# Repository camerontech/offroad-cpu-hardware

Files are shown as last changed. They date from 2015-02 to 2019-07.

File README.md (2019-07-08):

# Cameron Tech Offroad CPU

Here is the Eagle schematic and board layout for the CTAIM1. Software can be found here: https://github.com/camerontech/offroad-cpu

If picking up and assembling all of these parts yourself is a bit daunting, you can purchase a kit or pre-assembled
unit here: http://store.camerontech.io/products/offroad-cpu

Schematic

## Parts

**1 x ATMEGA328P-PU** [ATMEGA 328](http://amzn.to/2iHWBoK)

**1 x LCD** [SparkFun LCD-00709](https://www.sparkfun.com/products/709)

**1 x Multi-sensor** [10DOF Board](https://www.amazon.com/SUNKEE-1232055-Attitude-Indicator-L3G4200D/dp/B00CD239UG)

**1 x 5v Regulator** [Digikey MC7805CT-BPMS-ND]( http://www.digikey.com/product-search/en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)

**1 x 16MHz Clock Crystal** [Mouser 815-ABL-16-B2](http://www.mouser.com/Search/ProductDetail.aspx?R=ABL-16.000MHZ-B2virtualkey52750000virtualkey815-ABL-16-B2)

**1 x 10kΩ Potentiometer** [Digikey D4AA14-ND](http://www.digikey.com/product-search/en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)

**2 x 10µF Capacitor** [Digikey P975-ND](http://www.digikey.com/product-search/en/capacitors/aluminum-capacitors/131081?k=p975-ND)

**1 x 0.1F Capacitor** [Digikey 399-4266-ND](http://www.digikey.com/product-search/en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)

**2 x 22pF Capacitor** [Digikey 399-9723-ND](http://www.digikey.com/product-detail/en/C315C220K5G5TA/399-9723-ND/3726119)

**1 x NPN Transistor** [Mouser 512-2N3904BU](http://www.mouser.com/Search/ProductDetail.aspx?R=2N3904BUvirtualkey51210000virtualkey512-2N3904BU)

**1 x 40-pin Straight Header** [SparkFun PRT-00116](https://www.sparkfun.com/products/116)

**1 x 40-pin Right-angle Header** [SparkFun PRT-00553](https://www.sparkfun.com/products/553)

**1 x Three-way switch** [Three-way Rocker Switch](https://www.sparkfun.com/products/8184)

**1 x Three-way switch breakout board** [Breakout Board](https://oshpark.com/shared_projects/Y3Nexyzu)

That'll get you everything you need to get it working. You'll still need to connect the three-way switch to the board
somehow and get power in. 

A 4-wire JST connector hooks up the three-way switch to the circuit and also lets you disconnect it:

**1 x 4-pin JST Connector** [SparkFun PRT-09916](https://www.sparkfun.com/products/9916)

You can solder 12v right to your circuit, or use a 9v battery. If you want something less permanent then use a screw
terminal so you can unhook the wires again if necessary:

**1 x 2-pin screw terminal** [SparkFun PRT-08432](https://www.sparkfun.com/products/8432)

**1 x 9v Battery Strap** [Digikey 81-8K-ND](http://www.digikey.com/product-detail/en/81-8/81-8K-ND/303954)

Finally, unless you want to do a lot of wire-routing and excess soldering by hand and manually following the 
schematic to hook everything up, you can also get the circuit board that lays everything out nicely and attaches 
as a backpack to the LCD screen:

**1 x Offroad CPU Circuit Board** [Cameron Tech CTORD100](https://oshpark.com/shared_projects/I7EZdFw5)

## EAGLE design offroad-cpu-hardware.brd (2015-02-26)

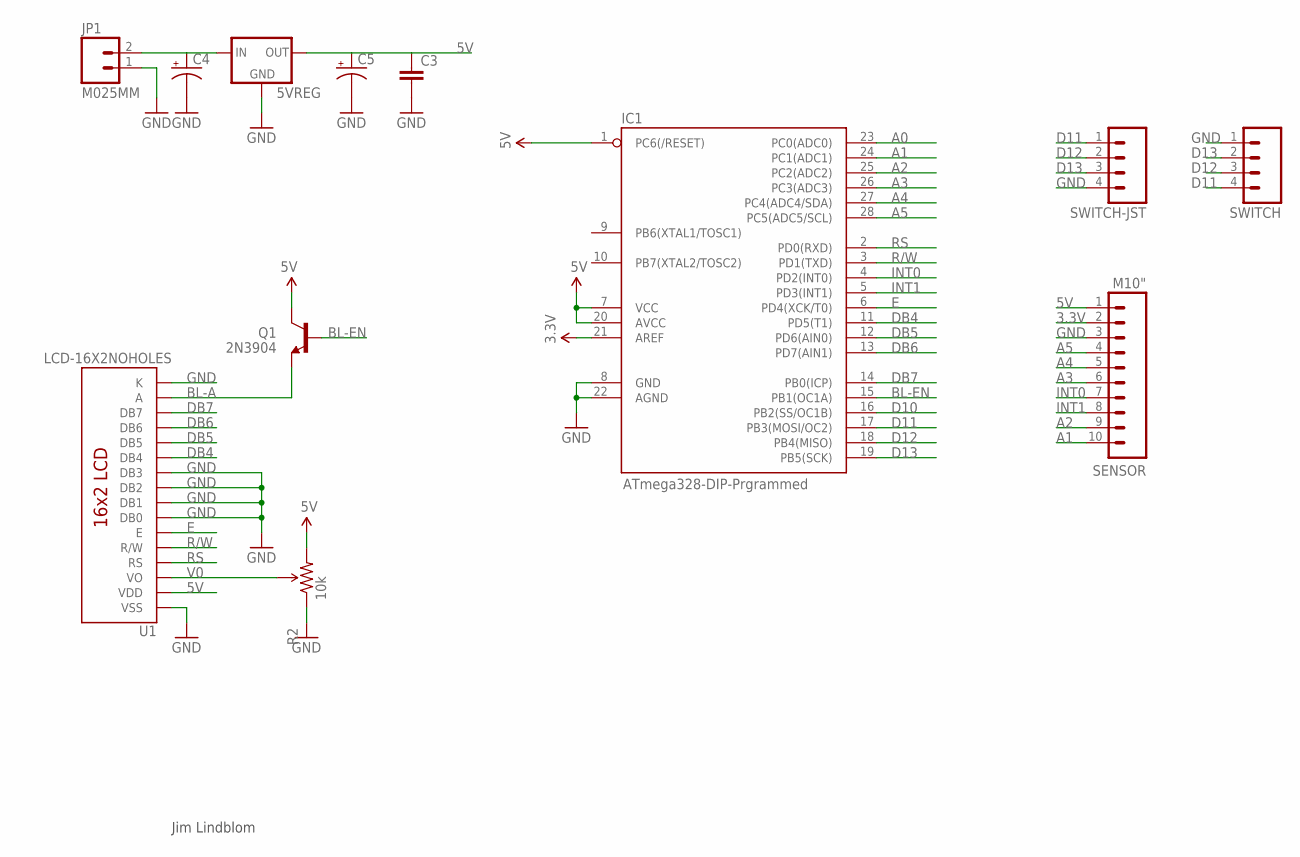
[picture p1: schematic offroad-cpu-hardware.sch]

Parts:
5VREG: 78XXS
C3: CAPPTH2; CAP-PTH-SMALL2
C4, C5: CAP_POLPTH2; CPOL-RADIAL-10UF-25V
IC1: ATmega328-DIP-Prgrammed; DIL28-3
JP1: M025MM; SCREWTERMINAL-5MM-2
Q1: 2N3904; TO-92
R2: 10k; TRIM_POT_PTH
SENSOR: M10"; 1X10
SWITCH: M04PTH; 1X04
SWITCH-JST: M04JST-PTH; JST-4-PTH
U1: LCD-16X2NOHOLES; LCD-16X2_NOHOLES

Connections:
3.3V: IC1.21 (AREF), SENSOR.2
5V: 5VREG.OUT, C3.1, C5.1 (+), IC1.1 (PC6(/RESET)), IC1.7 (VCC), IC1.20 (AVCC), Q1.3 (C), R2.3 (CW), SENSOR.1, U1.2 (VDD)
A0: IC1.23 (PC0(ADC0))
A1: IC1.24 (PC1(ADC1)), SENSOR.10
A2: IC1.25 (PC2(ADC2)), SENSOR.9
A3: IC1.26 (PC3(ADC3)), SENSOR.6
A4: IC1.27 (PC4(ADC4/SDA)), SENSOR.5
A5: IC1.28 (PC5(ADC5/SCL)), SENSOR.4
BL-A: Q1.1 (E), U1.15 (A)
BL-EN: IC1.15 (PB1(OC1A)), Q1.2 (B)
D10: IC1.16 (PB2(SS/OC1B))
D11: IC1.17 (PB3(MOSI/OC2)), SWITCH.4, SWITCH-JST.1
D12: IC1.18 (PB4(MISO)), SWITCH.3, SWITCH-JST.2
D13: IC1.19 (PB5(SCK)), SWITCH.2, SWITCH-JST.3
DB4: IC1.11 (PD5(T1)), U1.11 (DB4)
DB5: IC1.12 (PD6(AIN0)), U1.12 (DB5)
DB6: IC1.13 (PD7(AIN1)), U1.13 (DB6)
DB7: IC1.14 (PB0(ICP)), U1.14 (DB7)
E: IC1.6 (PD4(XCK/T0)), U1.6 (E)
GND: 5VREG.GND, C3.2, C4.2 (-), C5.2 (-), IC1.8 (GND), IC1.22 (AGND), JP1.1, R2.1 (CCW), SENSOR.3, SWITCH.1, SWITCH-JST.4, U1.1 (VSS), U1.7 (DB0), U1.8 (DB1), U1.9 (DB2), U1.10 (DB3), U1.16 (K)
INT0: IC1.4 (PD2(INT0)), SENSOR.7
INT1: IC1.5 (PD3(INT1)), SENSOR.8
R/W: IC1.3 (PD1(TXD)), U1.5 (R/W)
RS: IC1.2 (PD0(RXD)), U1.4 (RS)
V0: R2.2 (WIPER), U1.3 (VO)
VCC: 5VREG.IN, C4.1 (+), JP1.2

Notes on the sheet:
Jim Lindblom

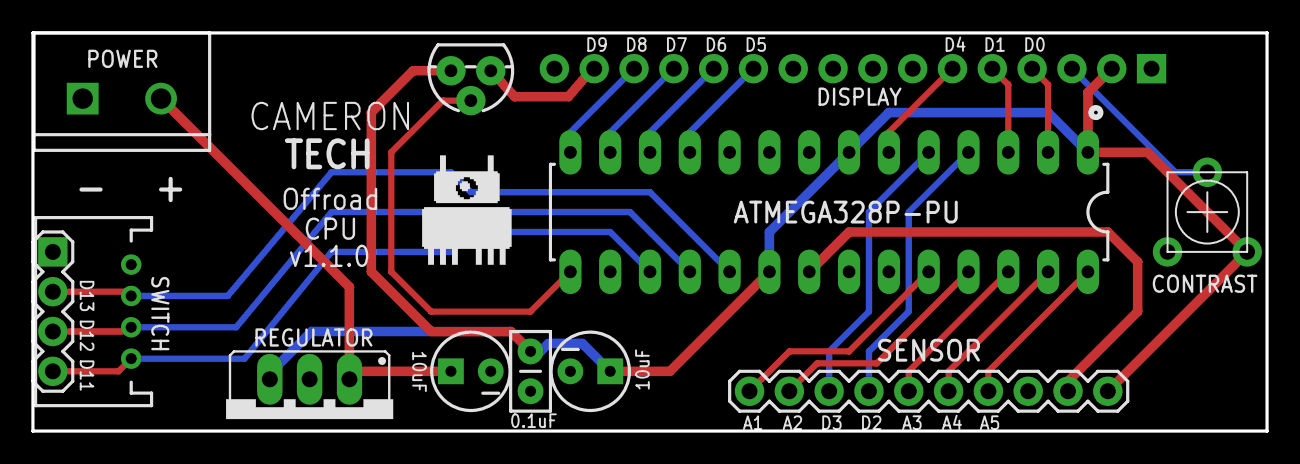
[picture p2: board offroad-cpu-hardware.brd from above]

Board: 2 copper layers, 78.7 x 25.4 mm, 12 parts (1 on the bottom side), 24 nets.

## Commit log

2013-09-25 Moved pins away from bottom edge, updated silkscreen
    [inclinometer-lcd-backpack.brd]
2013-10-06 Changes 3-way switch from 5V to GND, beefs up power connections to 0.016 wire width
    [inclinometer-lcd-backpack.brd, inclinometer-lcd-backpack.sch]
2013-10-09 Removes extra voltage smoothing caps (dual regulator board is doing this already)
    [inclinometer-lcd-backpack.brd, inclinometer-lcd-backpack.sch]
2013-10-09 Updates backside label of barometer SDA pin, moves branding
    [inclinometer-lcd-backpack.brd]
2013-10-14 Switches to 10DOF board from Sunkee
    http://www.amazon.com/gp/product/B00CD239UG/ref=oh_details_o01_s00_i00?ie=UTF8&psc=1
    [inclinometer-lcd-backpack.brd, inclinometer-lcd-backpack.sch]
2013-10-14 Adds screw terminals, connects currently unused pins
    [inclinometer-lcd-backpack.brd, inclinometer-lcd-backpack.sch]
2013-10-14 Nudged a wire out of the way of a couple pads
    [inclinometer-lcd-backpack.brd]
2013-11-14 Moves ATMEGA a tad so it's easier to remove, updates silkscreens on some pins
    [inclinometer-lcd-backpack.brd, inclinometer-lcd-backpack.sch]
2013-11-14 Adds schematic
2013-11-14 Renamed files to match repo
    [offroad-cpu-hardware.brd, offroad-cpu-hardware.sch]
2013-11-15 New sensor link
2015-02-26 Removes timing crystal and associated capacitors
    http://arduino.cc/en/Tutorial/ArduinoToBreadboard
    [offroad-cpu-hardware.brd, offroad-cpu-hardware.sch]
2019-07-08 Updated link to 10DOF board

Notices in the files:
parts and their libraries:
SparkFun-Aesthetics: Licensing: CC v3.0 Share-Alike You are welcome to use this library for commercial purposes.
